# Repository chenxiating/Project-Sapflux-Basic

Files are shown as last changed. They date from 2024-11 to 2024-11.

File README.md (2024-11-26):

# Project-Sapflux-Basic

Hardware designs for simplified PCBs for sapflux monitoring. Designed as a simplified PCB implementation of existing of hand wired designs created by [Xiating Chen](https://github.com/chenxiating) and [Bobby Schulz](https://github.com/bschulz1701).

# Repo Roadmap
<!-- #### [Documents](Documents/)

General document and image storage for repo and README -->

#### [Hardware](Hardware/)

Current board files (Eagle), and other electrical design documents

<!-- #### [Mechanical](Mechanical/)

Mechanical design files and assembly documents -->

#### [Production](Production/)

Contains the various Gerber and pick and place files required to have the Printed Circuit Boards (PCBs) manufactured or populated 

#### [Figures](Figures/)

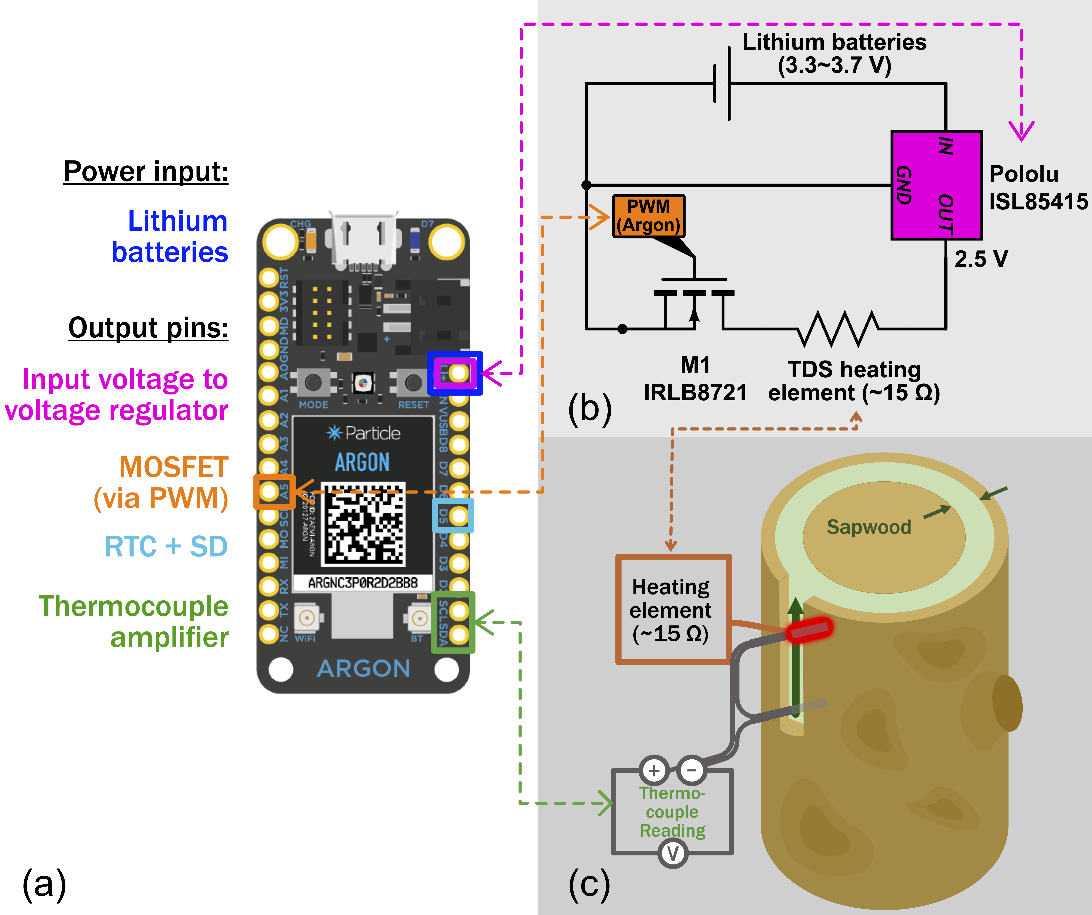
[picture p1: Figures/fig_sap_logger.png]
alt text for screen readers Schematic for wiring the sap flux sensors to a FeatherWing Tripler-compatible board (e.g., a Particle Argon development board)

Figure 1: Schematic for wiring the sap flux sensors to a FeatherWing Tripler-compatible board (e.g., a Particle Argon development board).

alt text for screen readers PCB wiring schematic and finished product for the sensing system
Figure 2: PCB wiring schematic and finished product for the sensing system.

alt text for screen readers Urban sap flux sensing system field deployment
Figure 3: Urban sap flux sensing system field deployment.

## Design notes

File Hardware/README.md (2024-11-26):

## Hardware

Multiple hardware variants of this design were created to leverage flexibility in the design process. Below is a description of the different variants.

#### [Alt - A](AltA/)

<!-- ![AltA Board](AltA/Sapflux-Basic_AltA-BOARD.pdf) -->
This board is a minor update of the design created by [Xiating Chen](https://github.com/chenxiating) and cleaned up by [Bobby Schulz](https://github.com/bschulz1701). 

#### [Alt - B](AltB/)

This board uses the same component set as [AltA](AltA/) but with an updated layout and some minor features added 

**Changes (vs AltA):**
- Addition of LED on output of heater line
- Updated board dimensions (kept constant for all other variants)
- Cutout and mounting holes for thermocouple amp
- Standard mounting of voltage regulator vs inverted mount on AltA

#### [Alt - C](AltC/)

This board adds support for all feature sets of onboard devices to allow for future firmware development to implement more advanced controls

**Changes (vs AltB):**
- Same mounting layout as AltB
- 9 pin header for thermocouple amp
	- All 4 alert lines from thermocouple amp are connected to feather
- Shutdown line on voltage regulator connected to feather

#### [Alt - D](AltD/)

This board adds all reasonable features while maintaining a simple hand soldered, through hole only design. Major addition here is the added support for soil moisture and rain gauge sensors

**Changes (vs AltC):**
- Same mounting layout as AltC
- Addition of 3 soil moisture sensor inputs 
	- Switchable power rail for soil moisture sensors with a MOSFET switch
	- LED placed on soil moisture power rail 
- Tipping bucket rain gauge connector added

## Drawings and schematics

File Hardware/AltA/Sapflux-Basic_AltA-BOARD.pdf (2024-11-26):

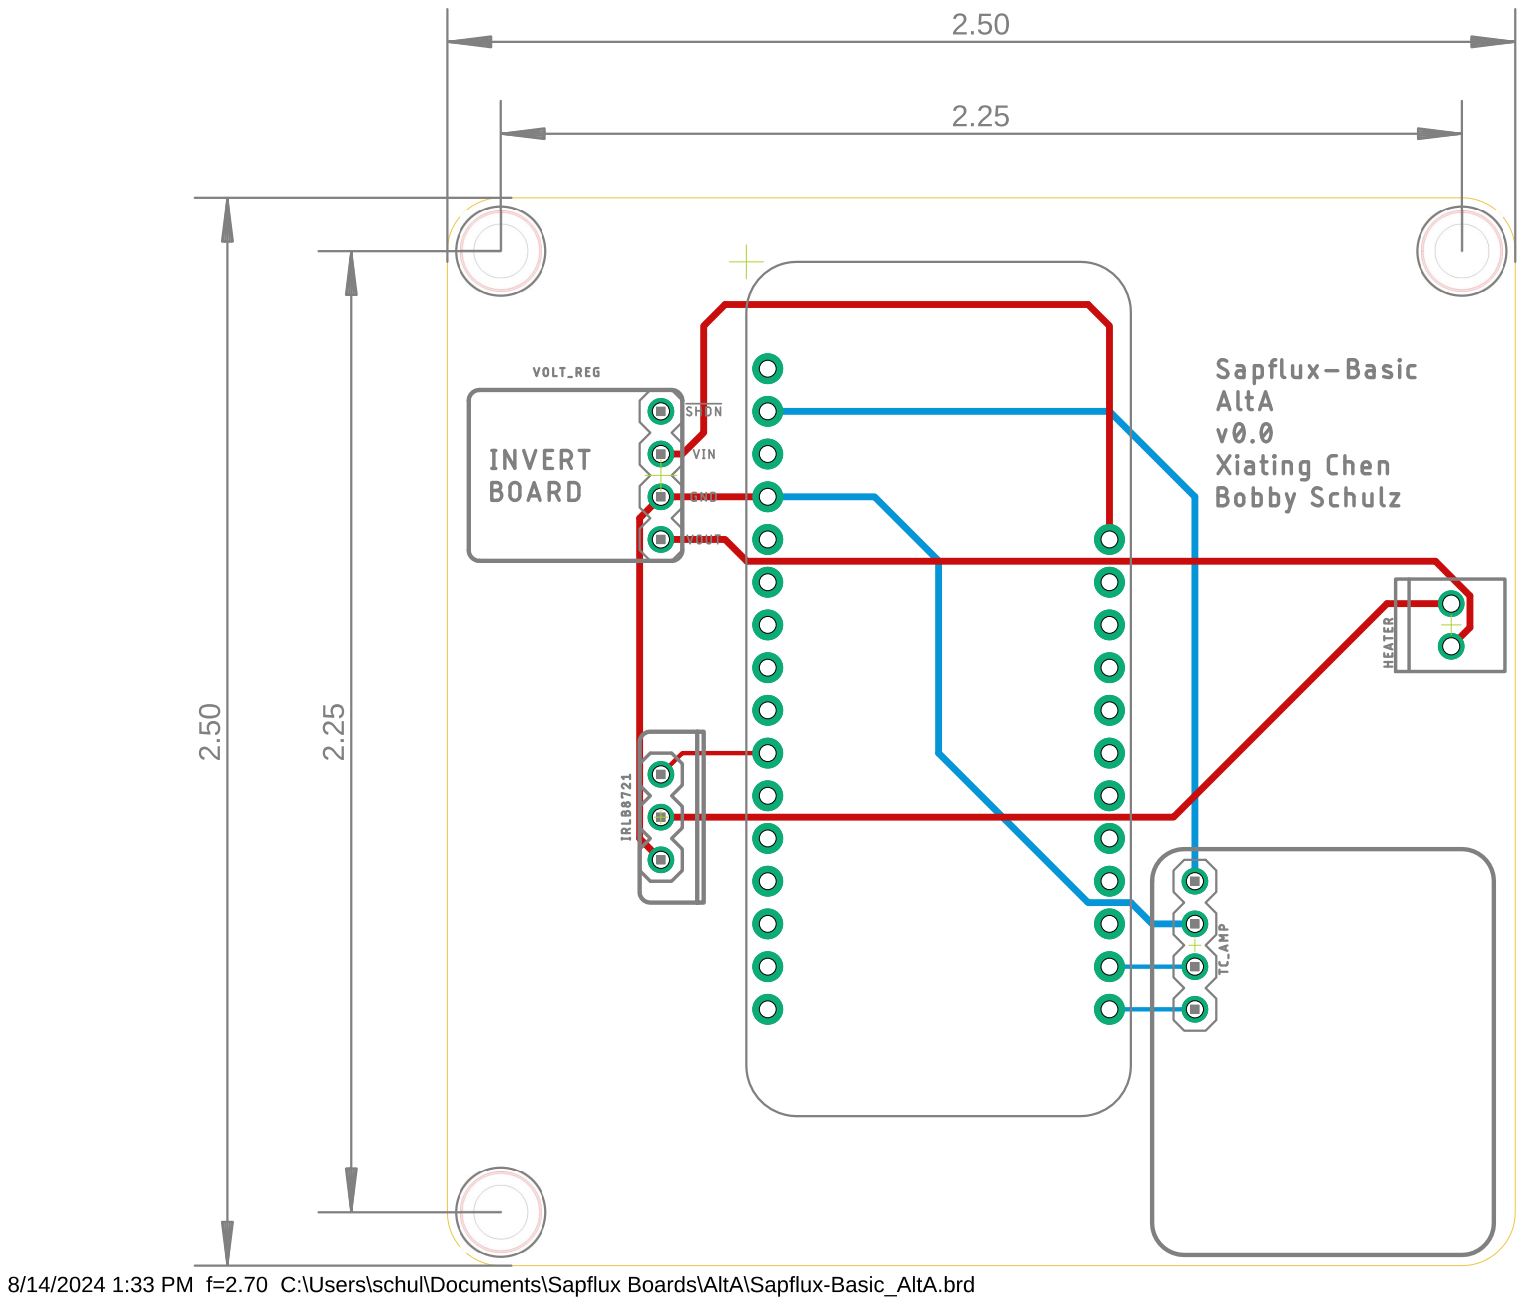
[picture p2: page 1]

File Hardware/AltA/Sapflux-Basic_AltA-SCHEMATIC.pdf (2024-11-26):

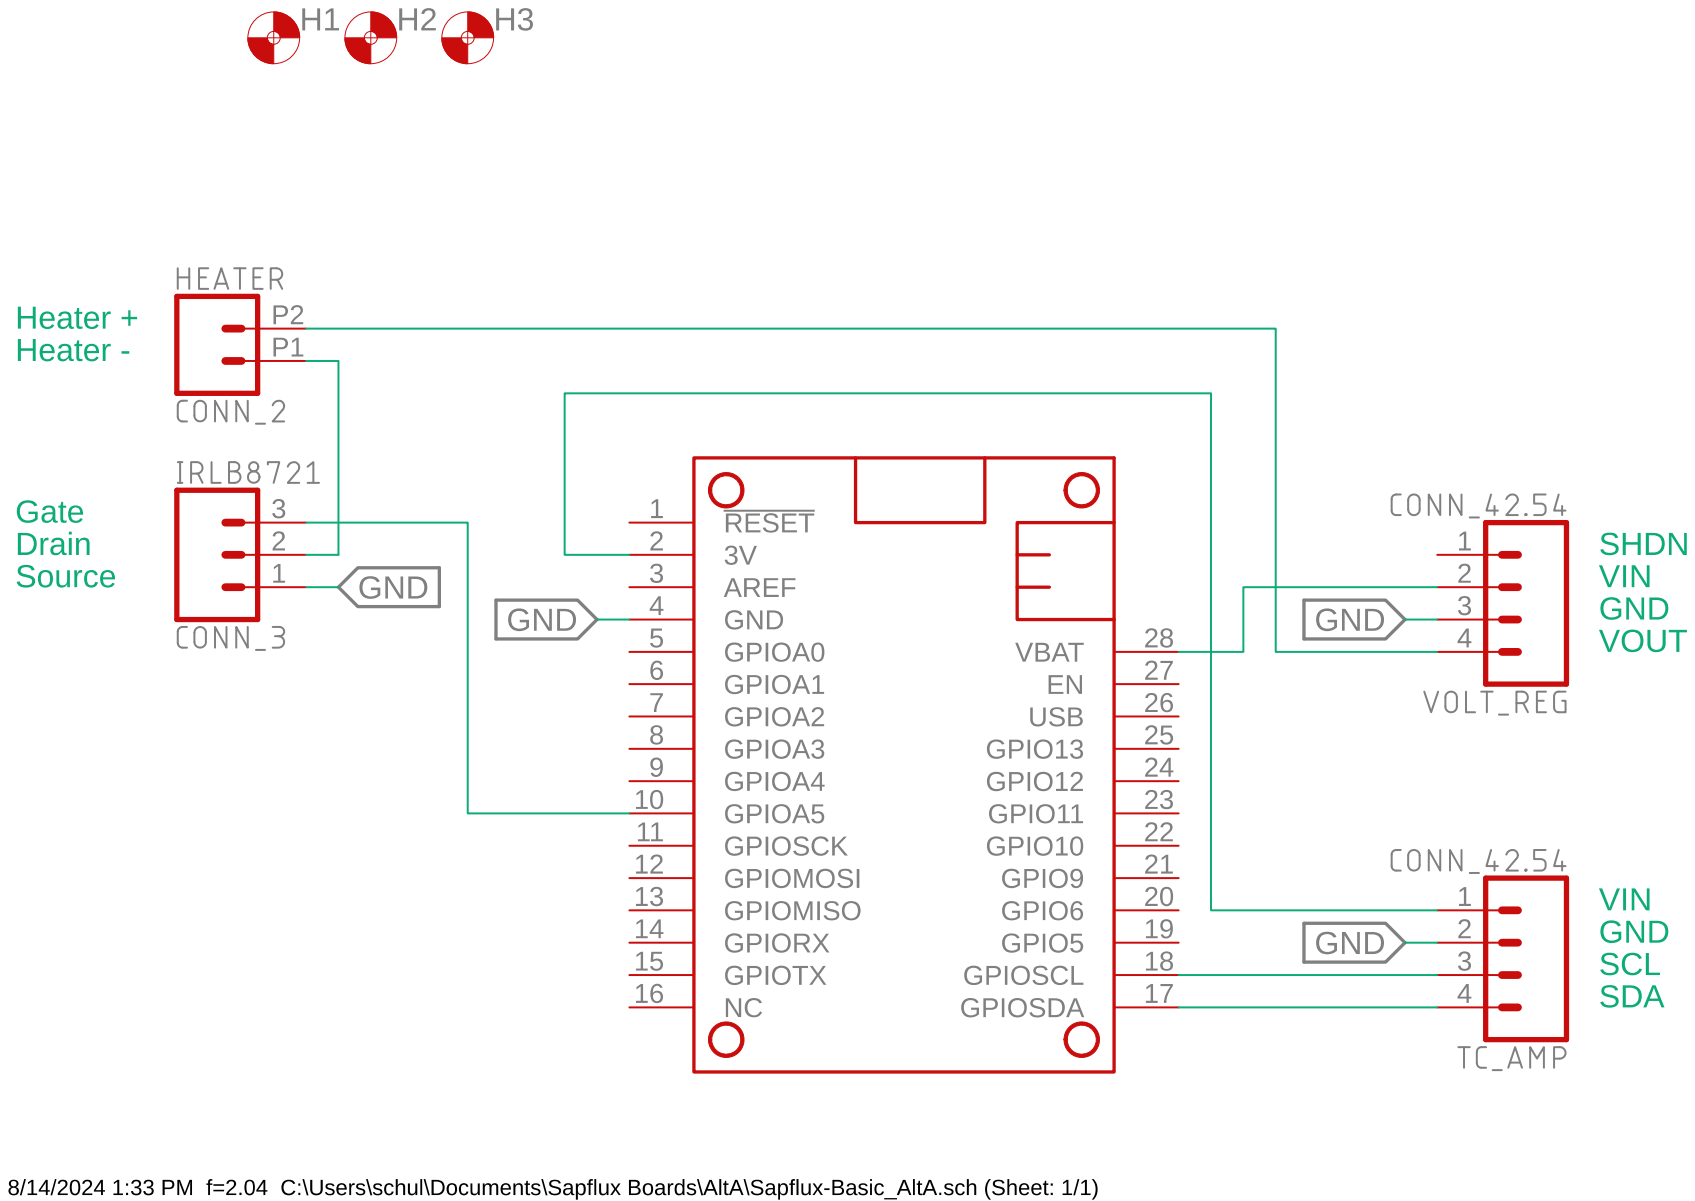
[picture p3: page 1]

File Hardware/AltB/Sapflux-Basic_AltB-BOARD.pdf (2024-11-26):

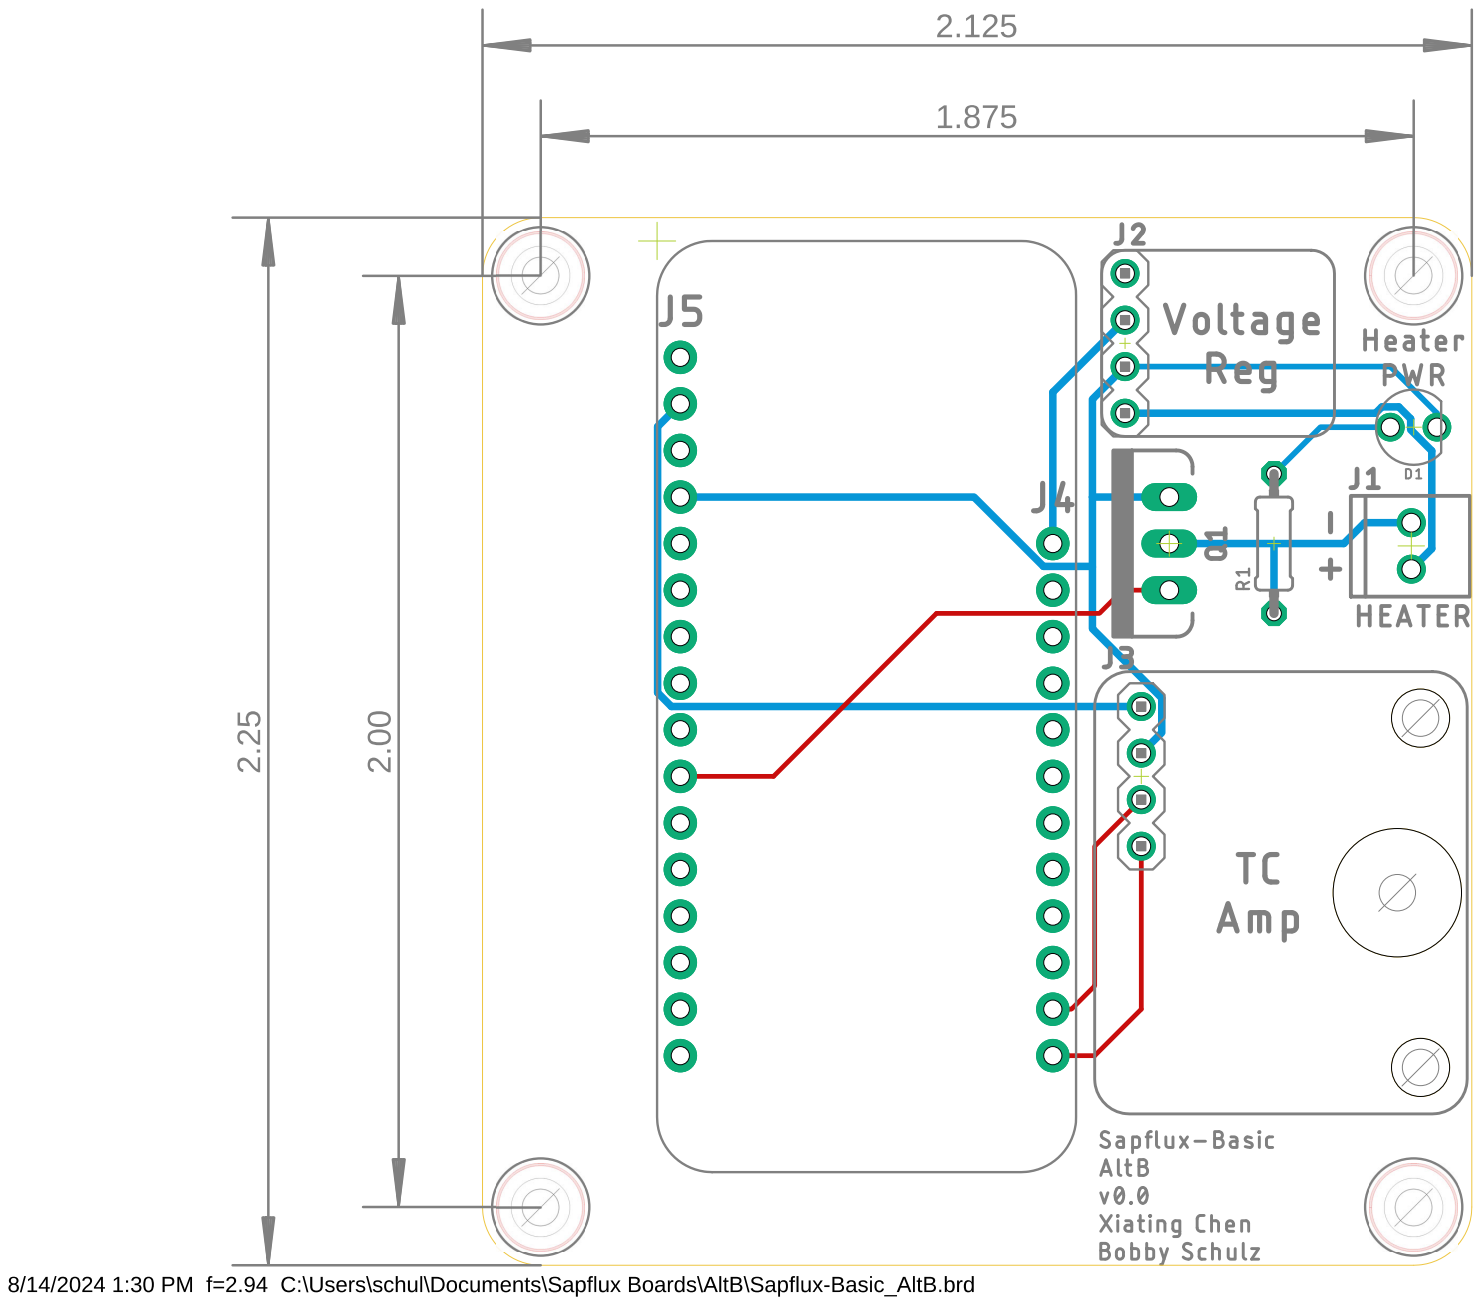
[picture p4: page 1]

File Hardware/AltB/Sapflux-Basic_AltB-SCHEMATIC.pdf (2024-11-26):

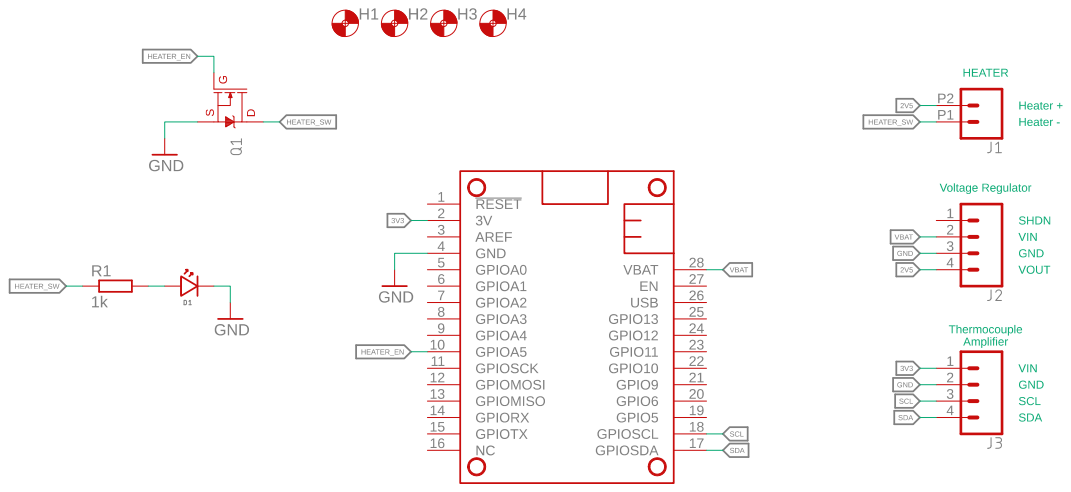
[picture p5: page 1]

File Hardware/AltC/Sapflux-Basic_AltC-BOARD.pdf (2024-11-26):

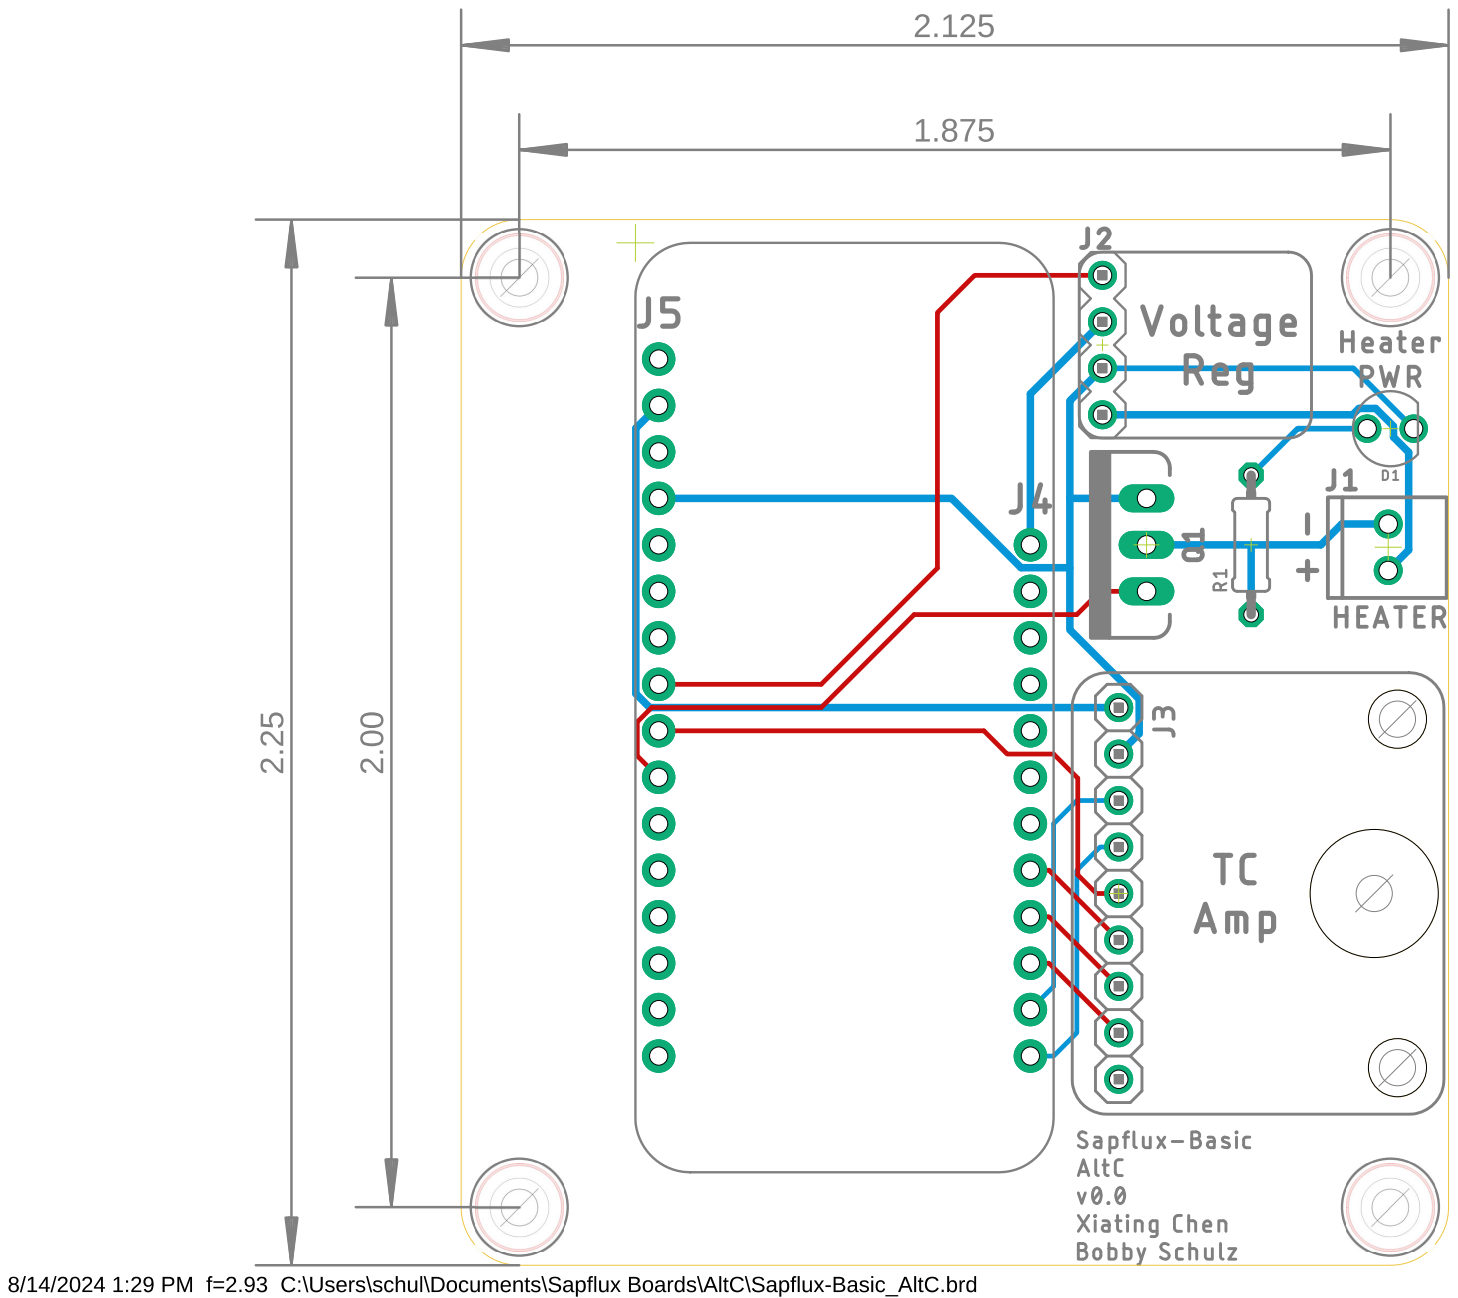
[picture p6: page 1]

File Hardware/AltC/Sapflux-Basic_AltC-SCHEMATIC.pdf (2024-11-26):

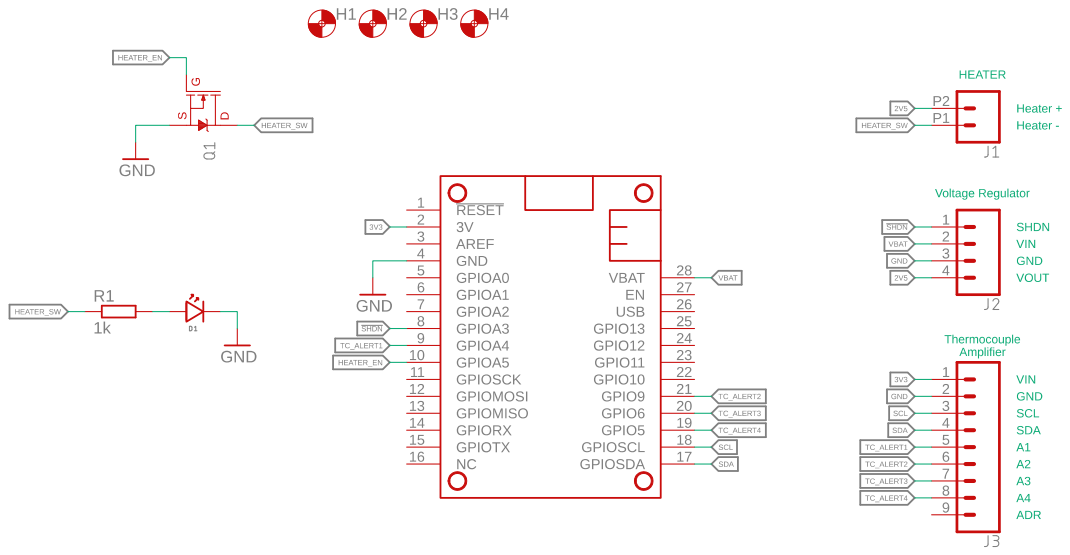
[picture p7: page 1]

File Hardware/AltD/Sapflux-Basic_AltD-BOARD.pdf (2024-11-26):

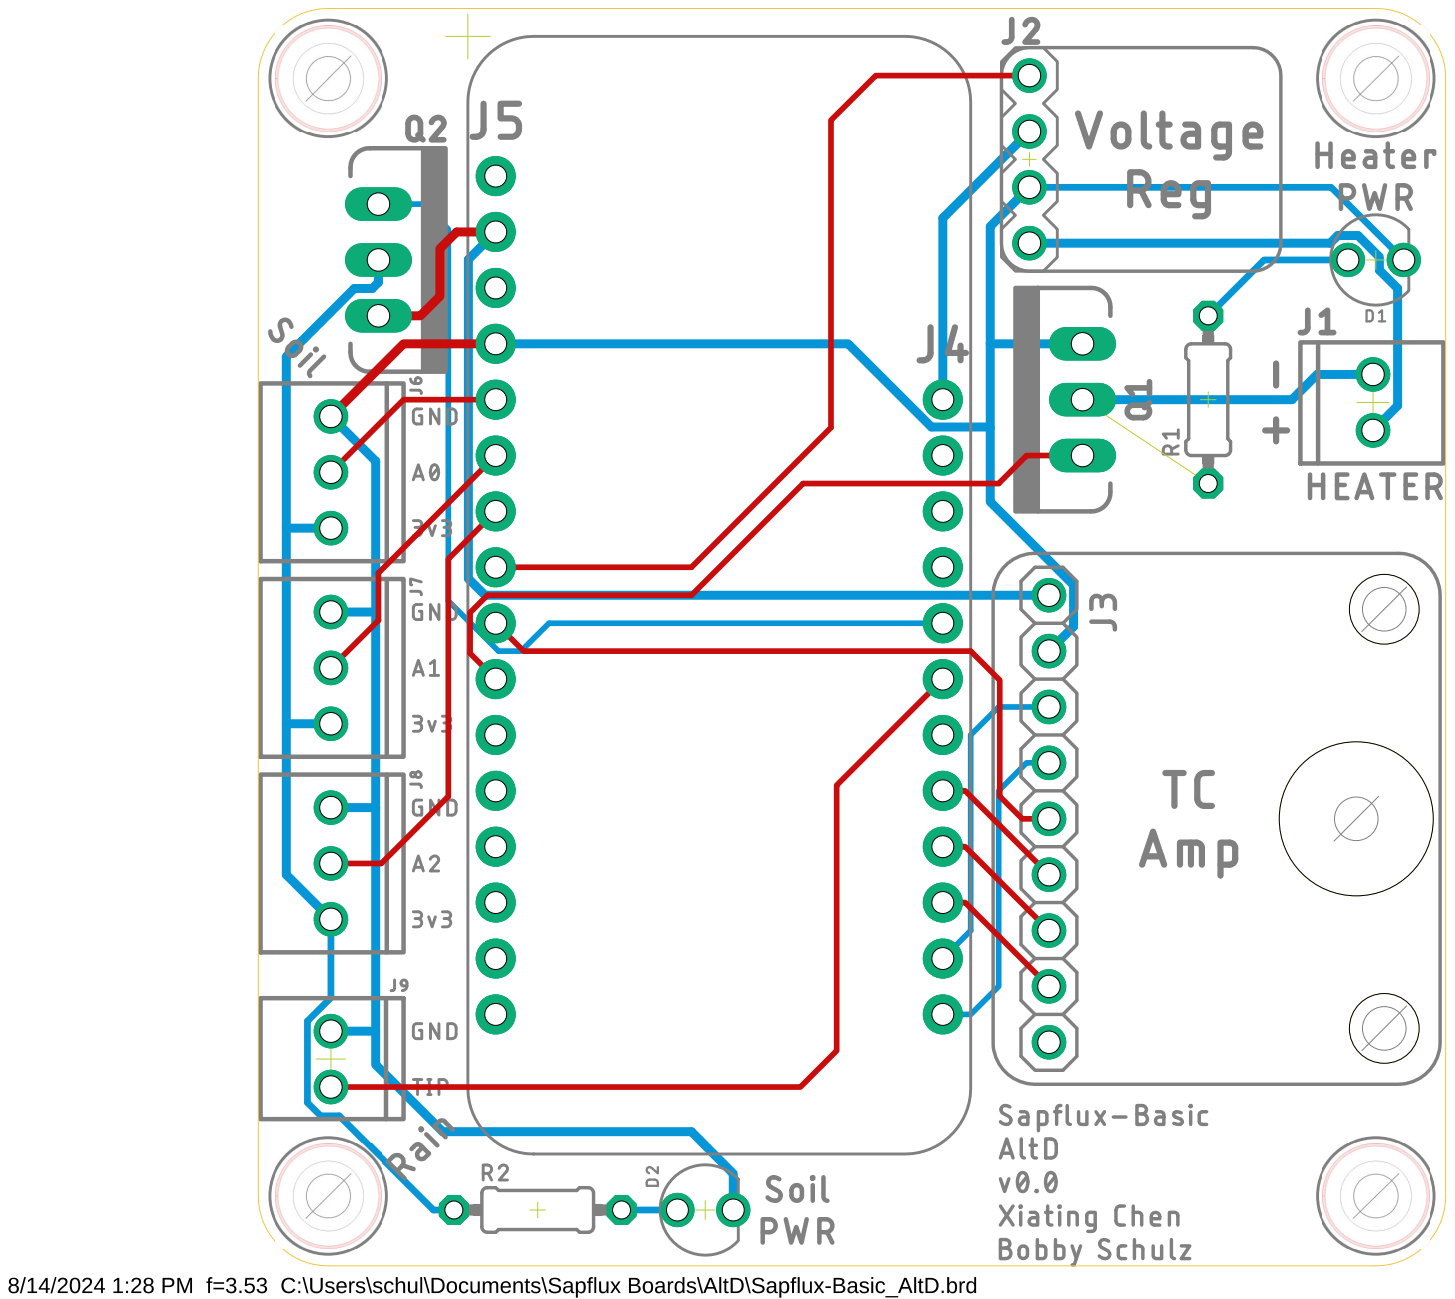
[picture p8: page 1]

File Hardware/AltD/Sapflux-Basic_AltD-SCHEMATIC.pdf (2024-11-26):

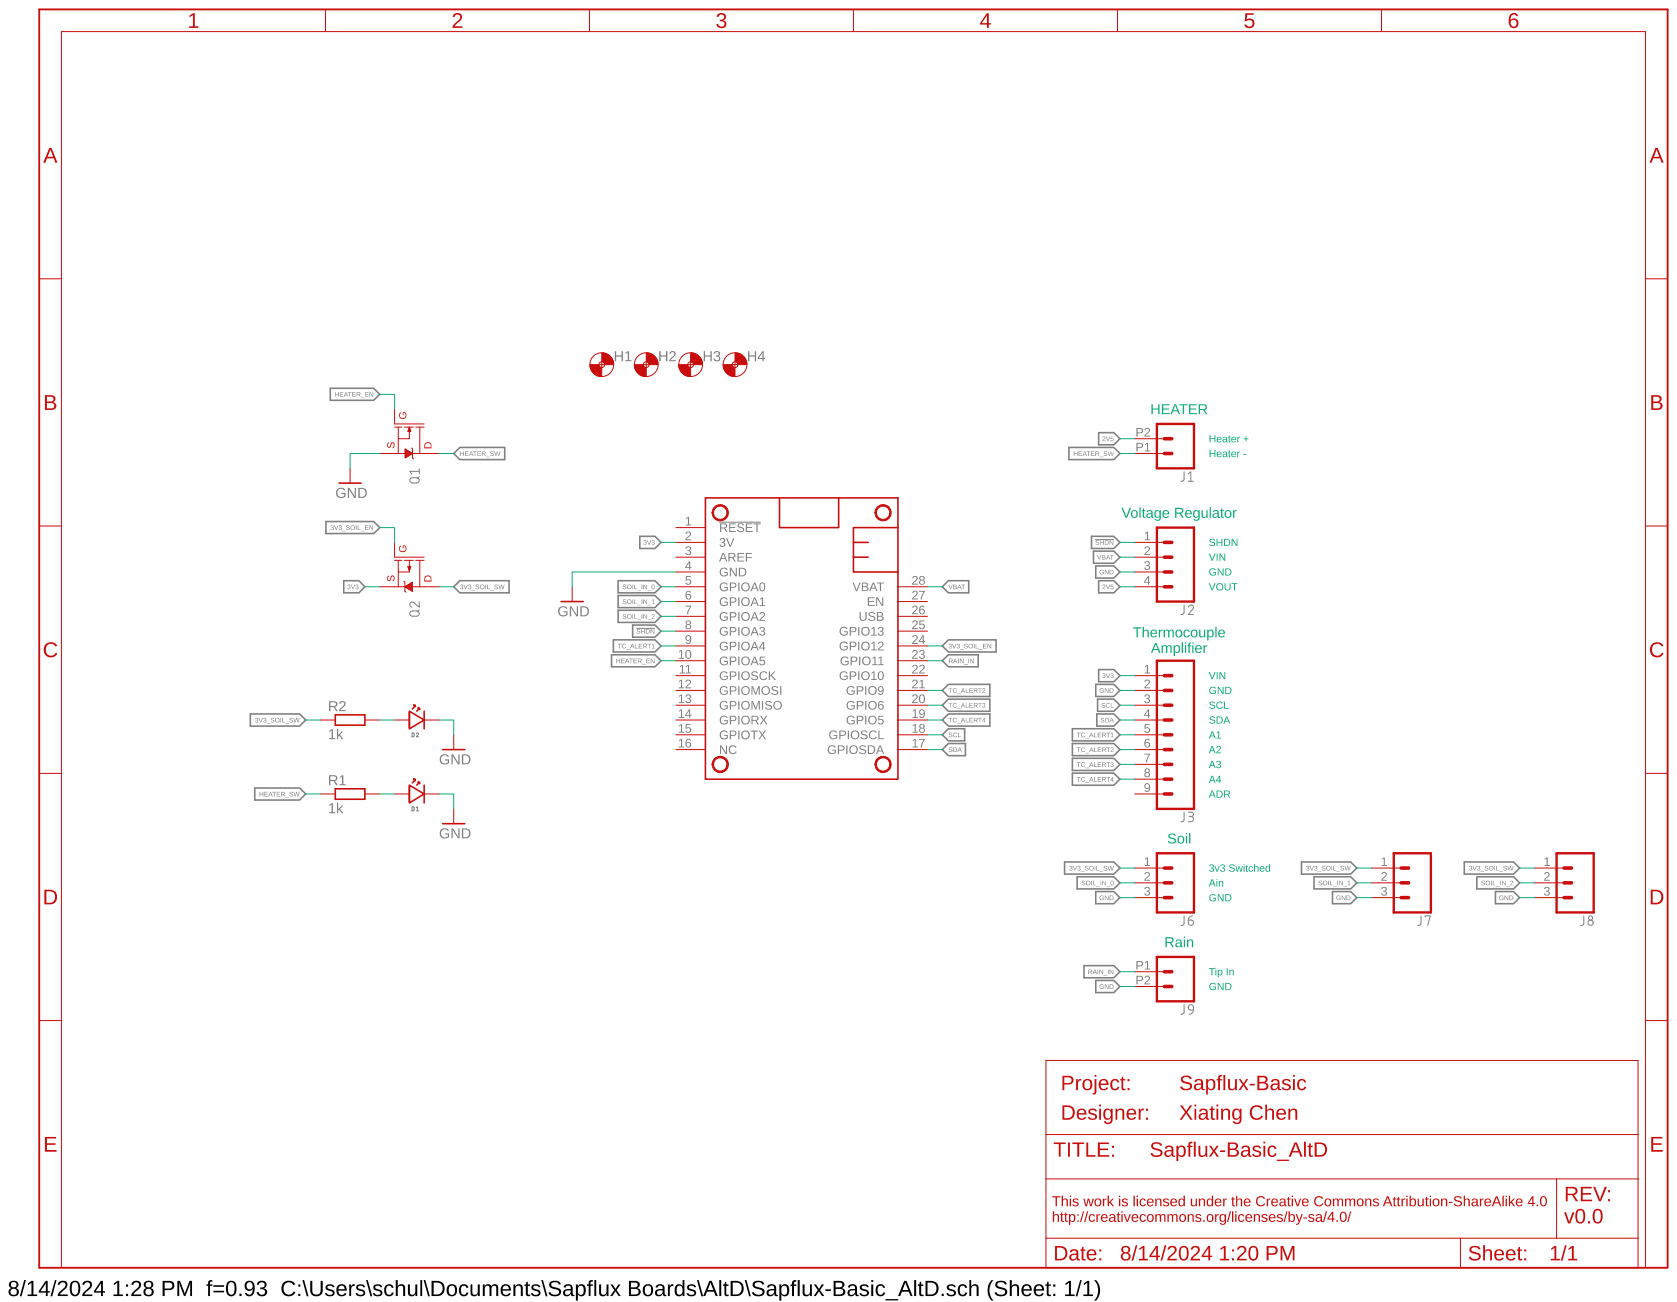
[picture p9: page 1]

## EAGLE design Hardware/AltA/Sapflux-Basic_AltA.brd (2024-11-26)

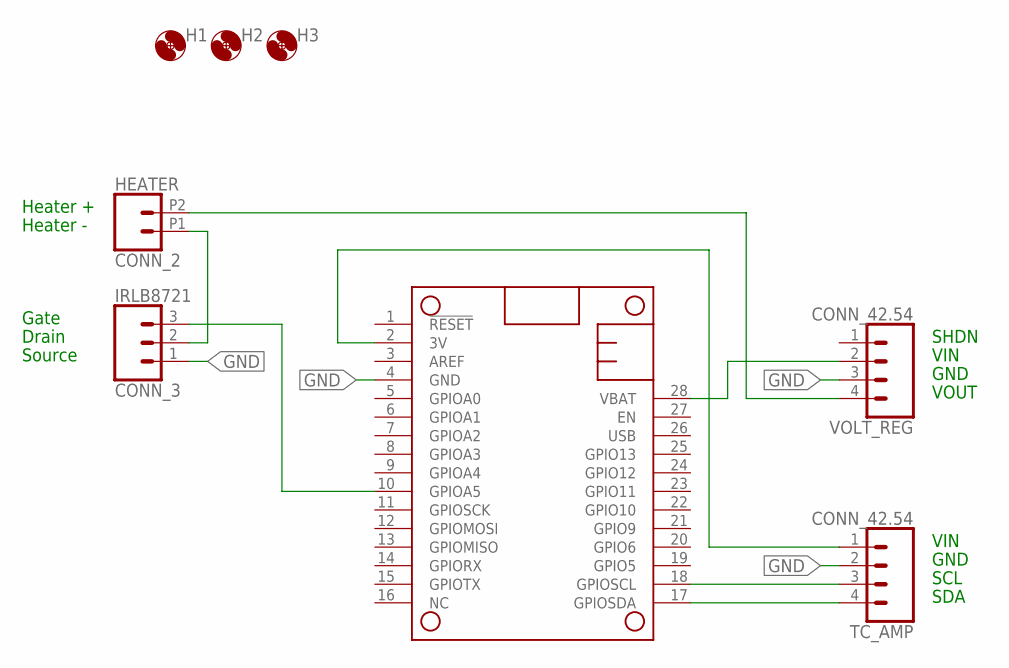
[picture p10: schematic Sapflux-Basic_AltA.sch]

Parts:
H1, H2, H3: MOUNTING_HOLE4_NP; 4_40
HEATER: CONN_2; 1X02_2.54_SCREWTERM_ROUND
IRLB8721: CONN_3; 1X03
MS1: FEATHERWINGLAYOUT; FEATHERWING_MIN
TC_AMP: CONN_42.54; 1X04
VOLT_REG: CONN_42.54; 1X04

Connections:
3V: MS1.2 (3V), TC_AMP.1
GND: IRLB8721.1, MS1.4 (GND), TC_AMP.2, VOLT_REG.3
unnamed: MS1.17 (GPIOSDA), TC_AMP.4
unnamed: MS1.18 (GPIOSCL), TC_AMP.3
unnamed: HEATER.P2 (2), VOLT_REG.4
unnamed: HEATER.P1 (1), IRLB8721.2
unnamed: IRLB8721.3, MS1.10 (GPIOA5)
VBAT: MS1.28 (VBAT), VOLT_REG.2

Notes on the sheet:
SHDN
VIN
GND
VOUT
SCL
SDA
Gate
Drain
Source
Heater +
Heater -

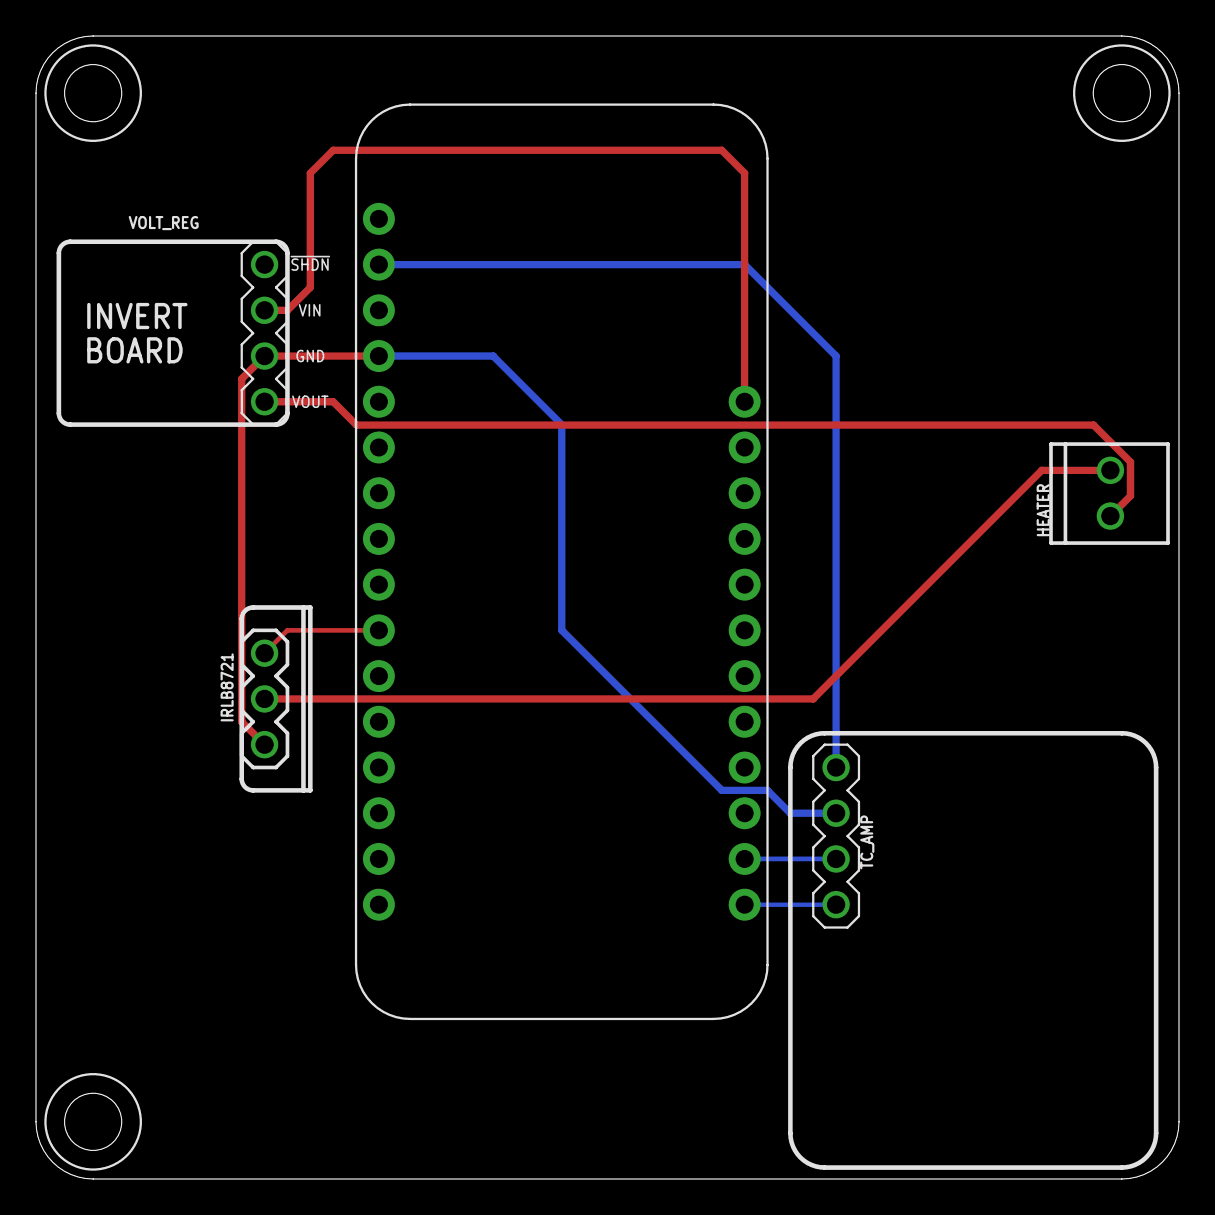
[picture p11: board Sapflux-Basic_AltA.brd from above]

Board: 2 copper layers, 63.5 x 63.5 mm, 8 parts (0 on the bottom side), 8 nets.

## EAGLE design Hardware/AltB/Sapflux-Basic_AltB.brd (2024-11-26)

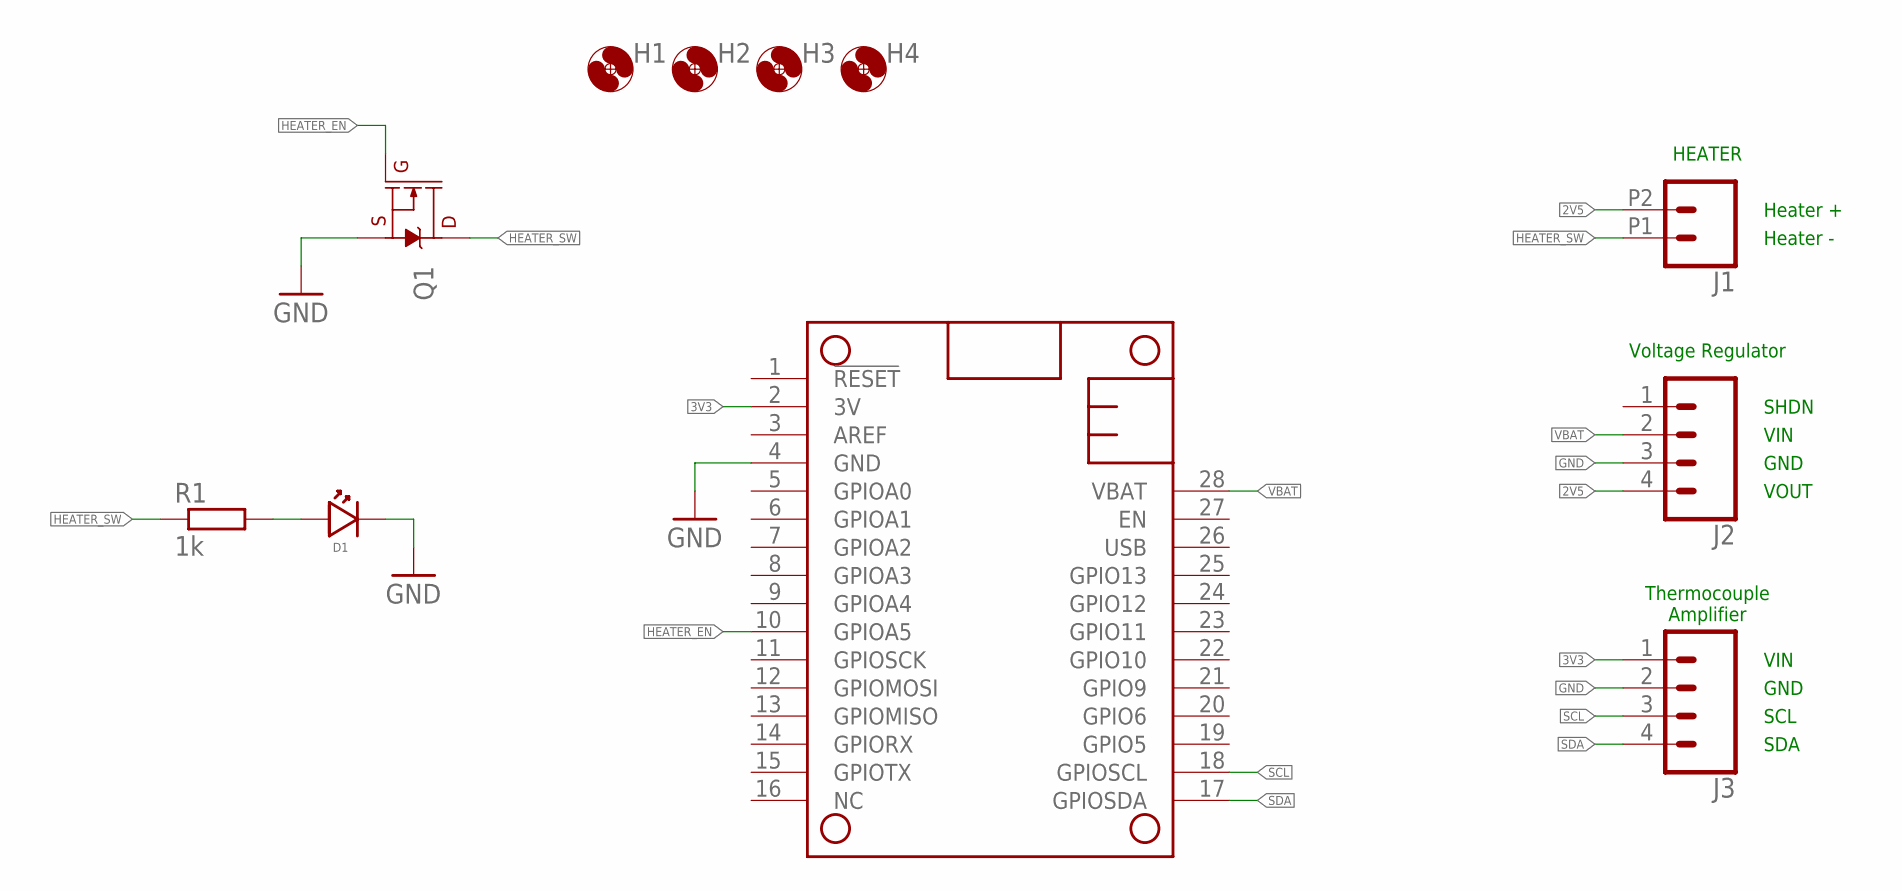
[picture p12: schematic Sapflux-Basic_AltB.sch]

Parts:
D1: LED3MM; LED_3MM
H1, H2, H3, H4: MOUNTING_HOLE4_NP; 4_40
J1: CONN_2; 1X02_2.54_SCREWTERM_ROUND
J2, J3: CONN_42.54; 1X04; MPN PH1-04-UA; DIGIKEY 2057-PH1-04-UA-ND
MS1: FEATHERWINGLAYOUT; FEATHERWING_MIN
Q1: 60V/32A/35mΩ; TO220V; MPN IRLB8721PBF; DIGIKEY IRLB8721PBF-ND
R1: 1k; 0204/7

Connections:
2V5: J1.P2 (2), J2.4
3V3: J3.1, MS1.2 (3V)
GND: D1.2 (CATHODE), J2.3, J3.2, MS1.4 (GND), Q1.3 (S)
HEATER_EN: MS1.10 (GPIOA5), Q1.1 (G)
HEATER_SW: J1.P1 (1), Q1.2 (D), R1.1
unnamed: D1.1 (ANODE), R1.2
SCL: J3.3, MS1.18 (GPIOSCL)
SDA: J3.4, MS1.17 (GPIOSDA)
VBAT: J2.2, MS1.28 (VBAT)

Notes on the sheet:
SHDN
VIN
GND
VOUT
SCL
SDA
Heater +
Heater -
HEATER
Voltage Regulator
Thermocouple Amplifier

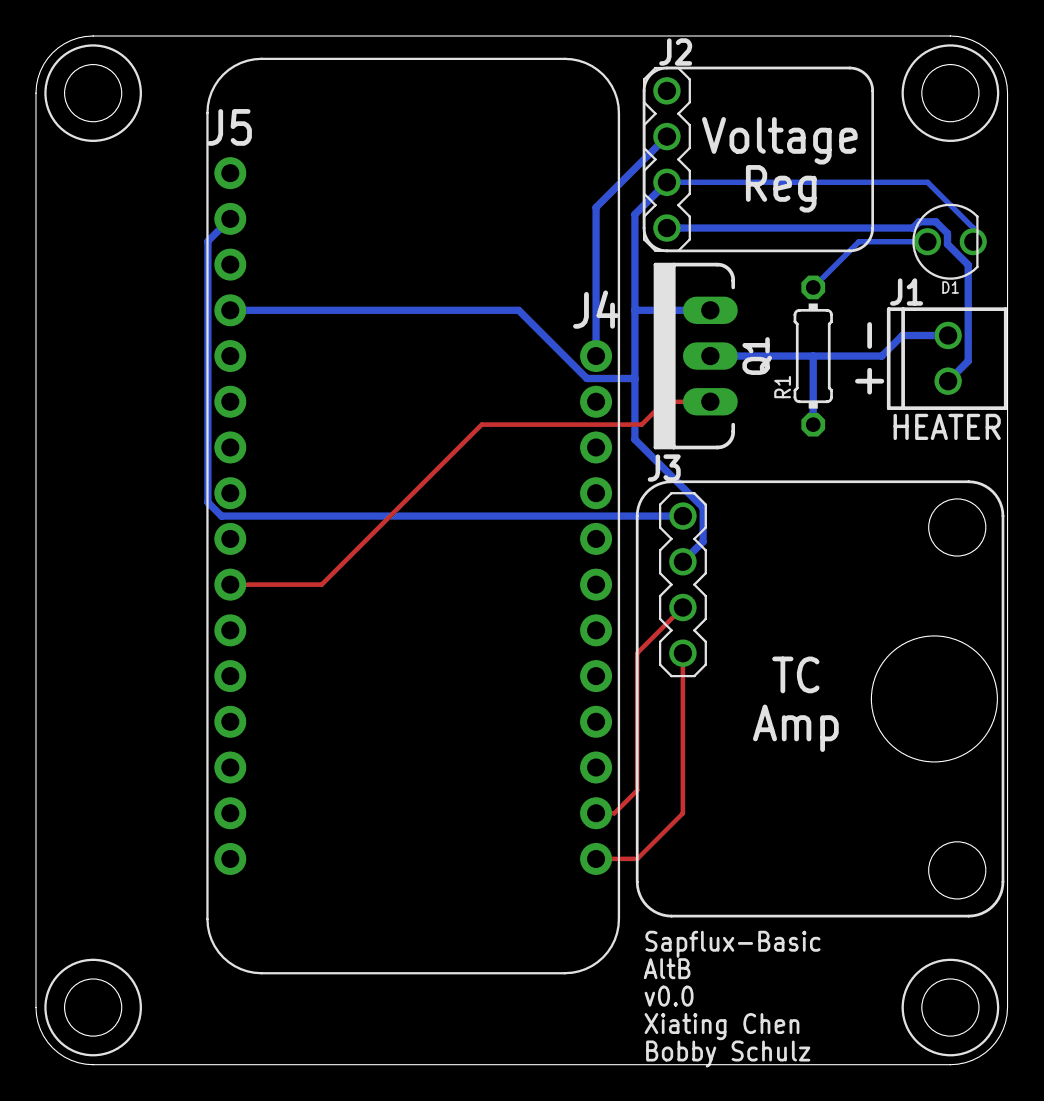
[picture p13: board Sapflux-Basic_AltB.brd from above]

Board: 2 copper layers, 54.0 x 57.1 mm, 11 parts (0 on the bottom side), 9 nets.

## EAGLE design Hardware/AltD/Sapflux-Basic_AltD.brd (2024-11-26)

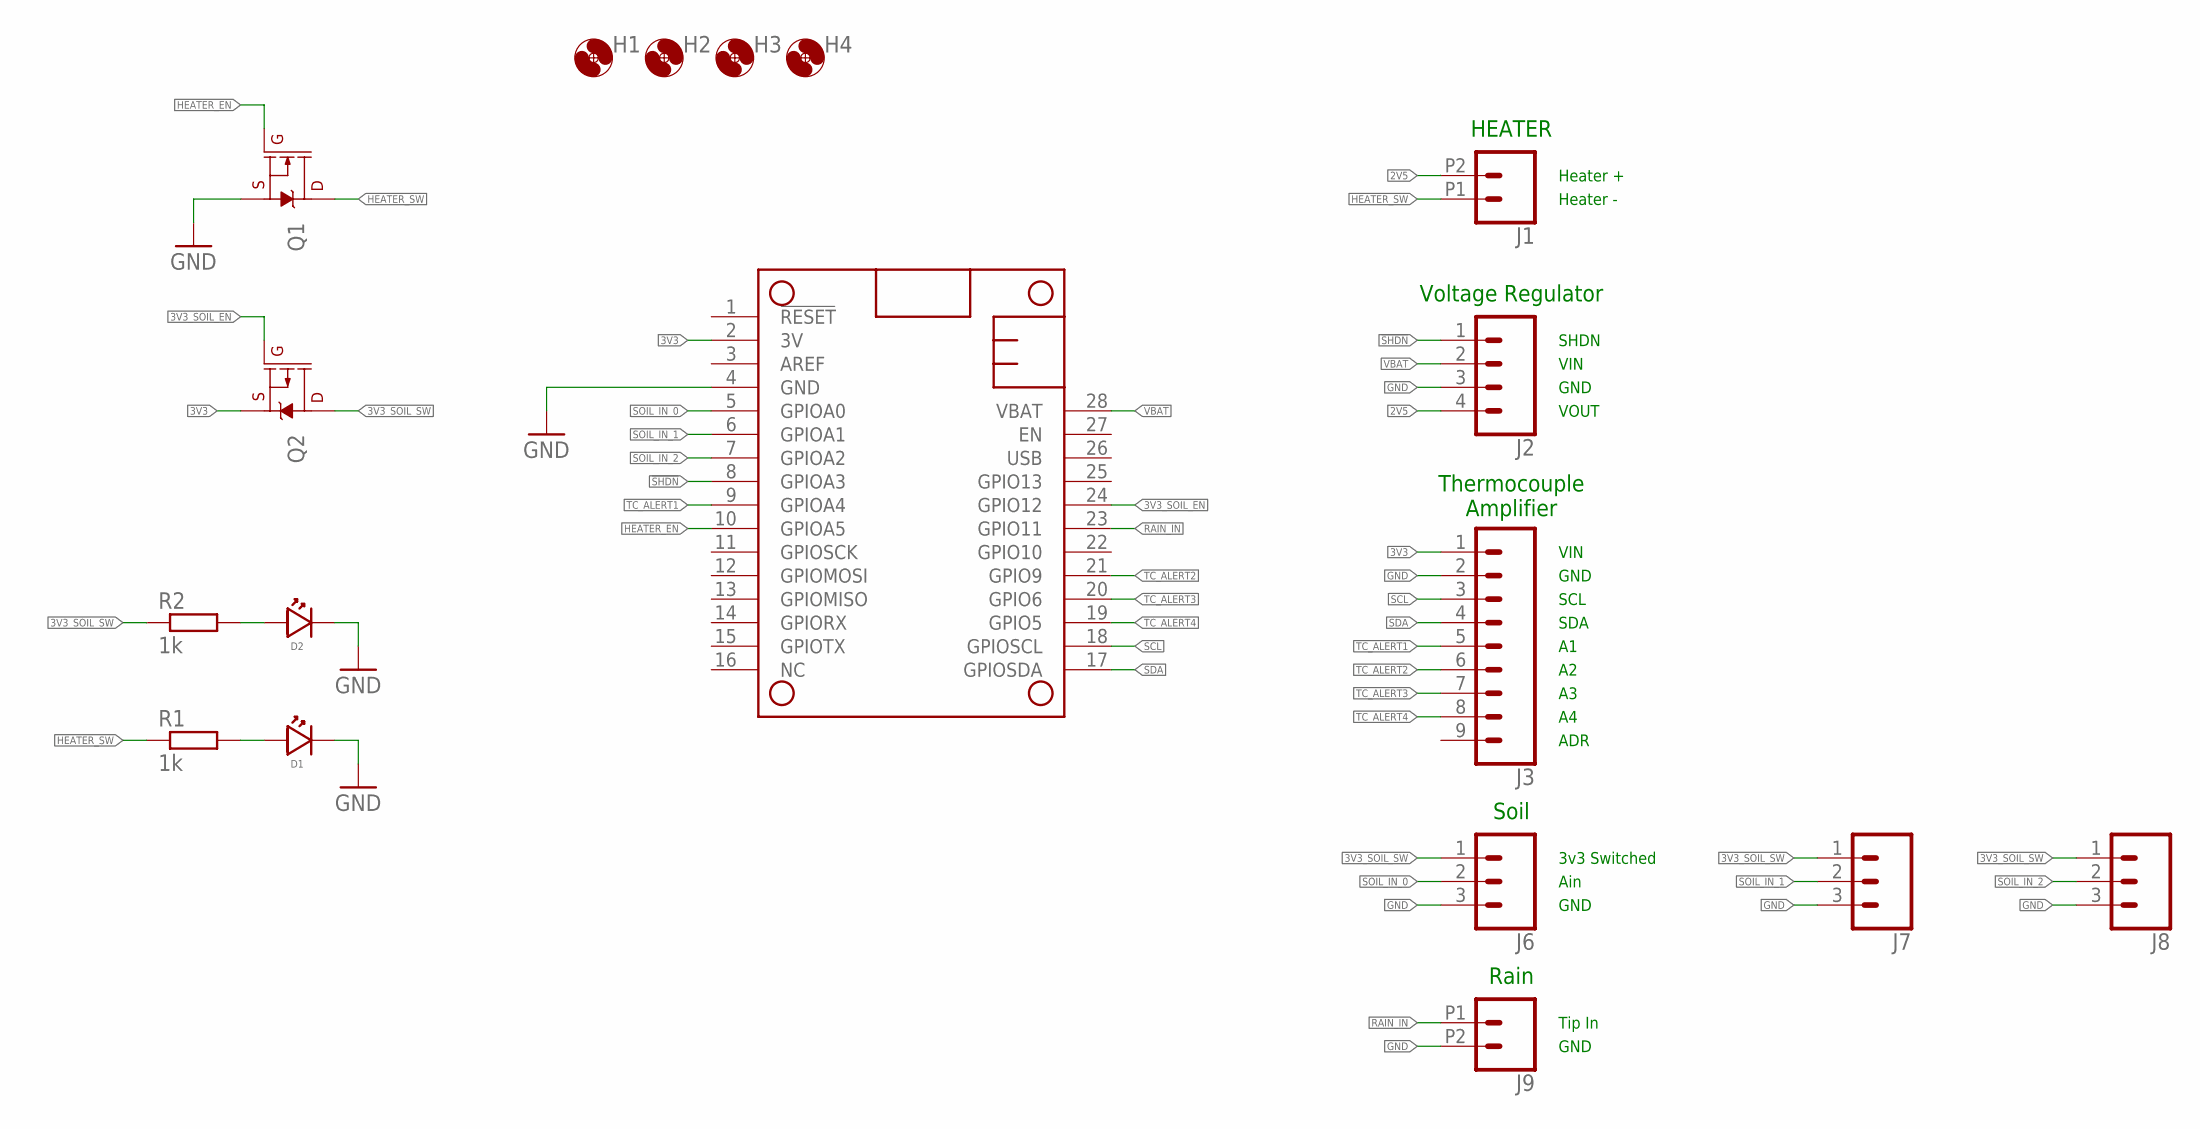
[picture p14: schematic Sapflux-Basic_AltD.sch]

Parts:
D1, D2: LED3MM; LED_3MM
H1, H2, H3, H4: MOUNTING_HOLE4_NP; 4_40
J1: CONN_2; 1X02_2.54_SCREWTERM_ROUND
J2: CONN_42.54; 1X04; MPN PH1-04-UA; DIGIKEY 2057-PH1-04-UA-ND
J3: CONN_9; 1X09; MPN PH1-09-UA; DIGIKEY 2057-PH1-09-UA-ND
J6, J7, J8: CONN_32.54_SCREW; 1X03_SCREW
J9: CONN_022.54_SCREW_ROUND; 1X02_2.54_SCREWTERM_ROUND
MS1: FEATHERWINGLAYOUT; FEATHERWING_MIN
Q1: 60V/32A/35mΩ; TO220V; MPN IRLB8721PBF; DIGIKEY IRLB8721PBF-ND
Q2: 24A/20V/50mΩ; TO220V; MPN SUP53P06-20-E3; DIGIKEY SUP53P06-20-E3-ND
R1, R2: 1k; 0204/7

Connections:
2V5: J1.P2 (2), J2.4
3V3: J3.1, MS1.2 (3V), Q2.3 (S)
3V3_SOIL_EN: MS1.24 (GPIO12), Q2.1 (G)
3V3_SOIL_SW: J6.1, J7.1, J8.1, Q2.2 (D), R2.1
!SHDN: J2.1, MS1.8 (GPIOA3)
GND: D1.2 (CATHODE), D2.2 (CATHODE), J2.3, J3.2, J6.3, J7.3, J8.3, J9.P2 (2), MS1.4 (GND), Q1.3 (S)
HEATER_EN: MS1.10 (GPIOA5), Q1.1 (G)
HEATER_SW: J1.P1 (1), Q1.2 (D), R1.1
unnamed: D2.1 (ANODE), R2.2
unnamed: D1.1 (ANODE), R1.2
RAIN_IN: J9.P1 (1), MS1.23 (GPIO11)
SCL: J3.3, MS1.18 (GPIOSCL)
SDA: J3.4, MS1.17 (GPIOSDA)
SOIL_IN_0: J6.2, MS1.5 (GPIOA0)
SOIL_IN_1: J7.2, MS1.6 (GPIOA1)
SOIL_IN_2: J8.2, MS1.7 (GPIOA2)
TC_ALERT1: J3.5, MS1.9 (GPIOA4)
TC_ALERT2: J3.6, MS1.21 (GPIO9)
TC_ALERT3: J3.7, MS1.20 (GPIO6)
TC_ALERT4: J3.8, MS1.19 (GPIO5)
VBAT: J2.2, MS1.28 (VBAT)

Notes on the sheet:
SHDN
VIN
GND
VOUT
SCL
SDA
Heater +
Heater -
HEATER
Voltage Regulator
Thermocouple Amplifier
ADR
Rain
Soil
Ain
3v3 Switched
Tip In

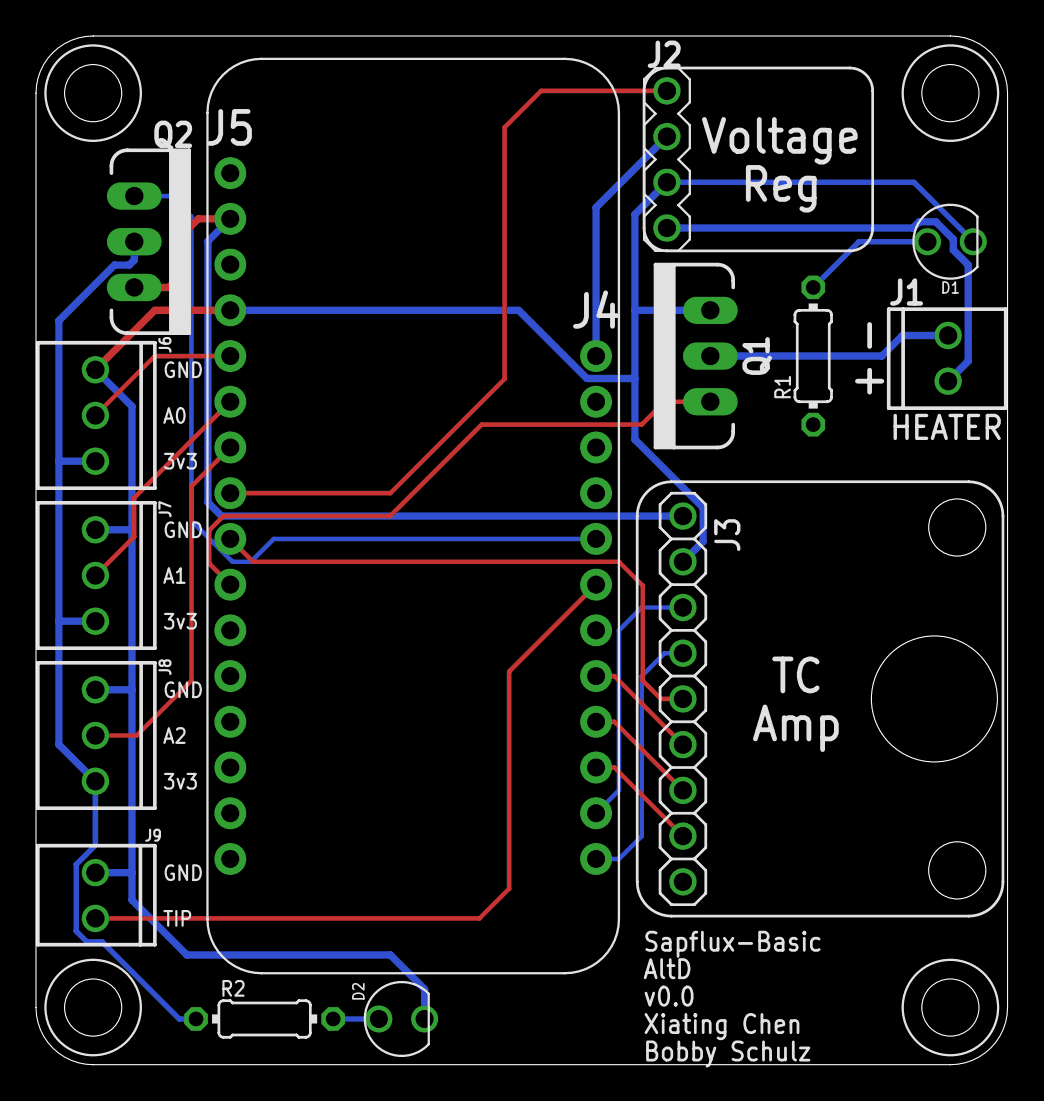
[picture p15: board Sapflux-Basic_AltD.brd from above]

Board: 2 copper layers, 54.0 x 57.1 mm, 18 parts (0 on the bottom side), 21 nets.

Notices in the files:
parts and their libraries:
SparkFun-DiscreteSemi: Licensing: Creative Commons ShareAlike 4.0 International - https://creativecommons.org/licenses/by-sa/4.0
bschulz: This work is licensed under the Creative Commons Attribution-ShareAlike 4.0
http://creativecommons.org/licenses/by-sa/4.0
